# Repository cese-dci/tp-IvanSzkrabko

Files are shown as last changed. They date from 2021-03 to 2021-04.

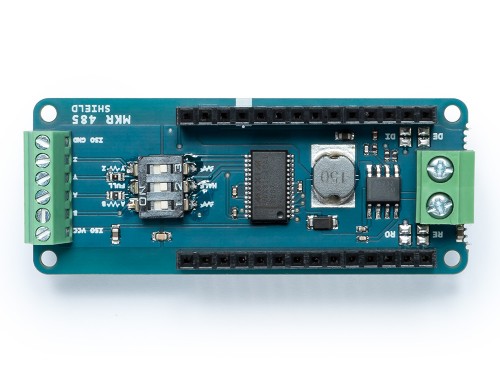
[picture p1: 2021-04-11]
Documentos/Superior.jpg

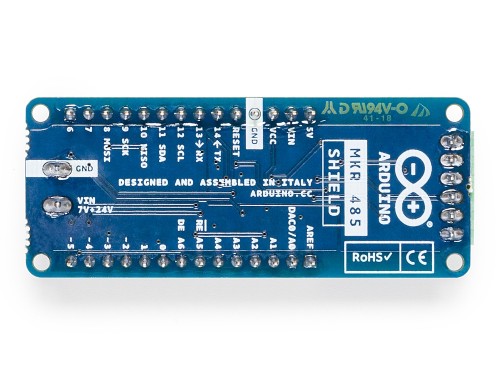
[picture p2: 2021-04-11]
Documentos/Inferior.jpg

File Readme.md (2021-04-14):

Shield RS485 para placa MKR1_Wifi1010
================================================

[][cc-by-sa]

This work is licensed under a
[Creative Commons Attribution-ShareAlike 4.0 International License][cc-by-sa].

[][cc-by-sa]

[cc-by-sa]: http://creativecommons.org/licenses/by-sa/4.0/
[cc-by-sa-image]: https://licensebuttons.net/l/by-sa/4.0/88x31.png
[cc-by-sa-shield]: https://img.shields.io/badge/License-CC%20BY--SA%204.0-lightgrey.svg

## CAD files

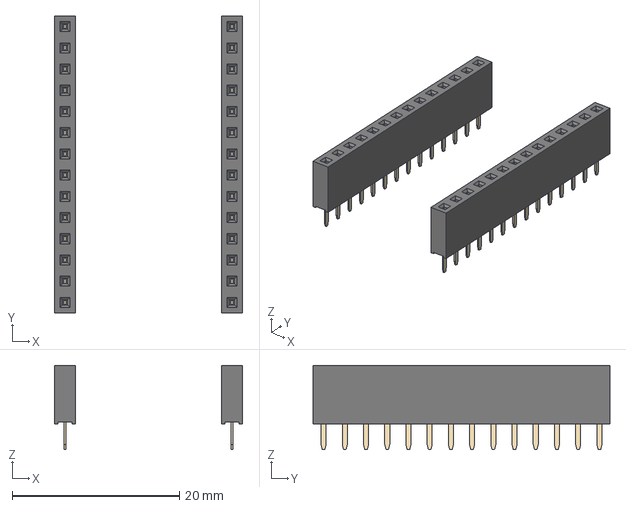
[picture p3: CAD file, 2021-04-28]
3dshapes/MKR_Sockets_v1.step
22.5 x 35.6 x 10.1 mm

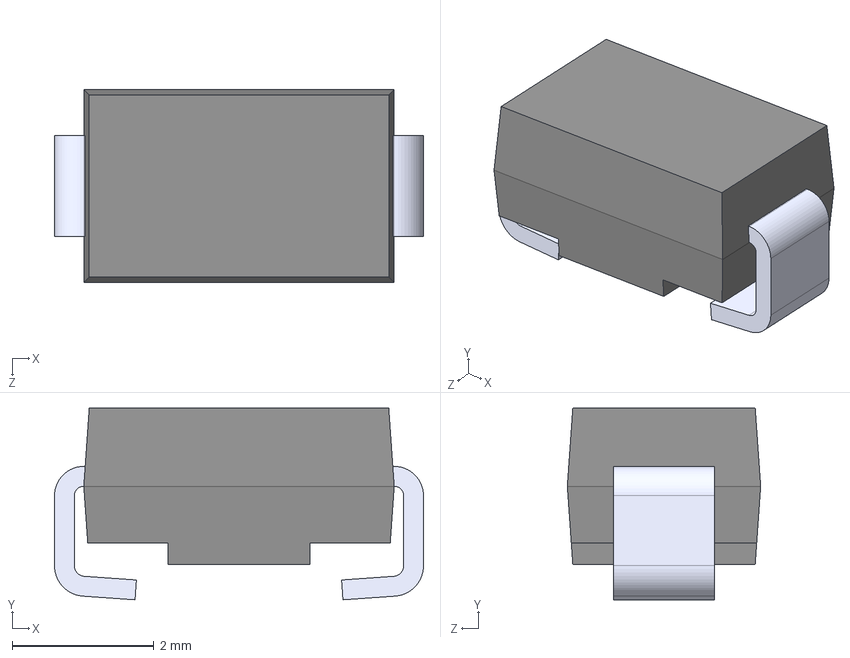
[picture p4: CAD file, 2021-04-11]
3dshapes/DO_214AC.step
5.20 x 2.70 x 2.73 mm

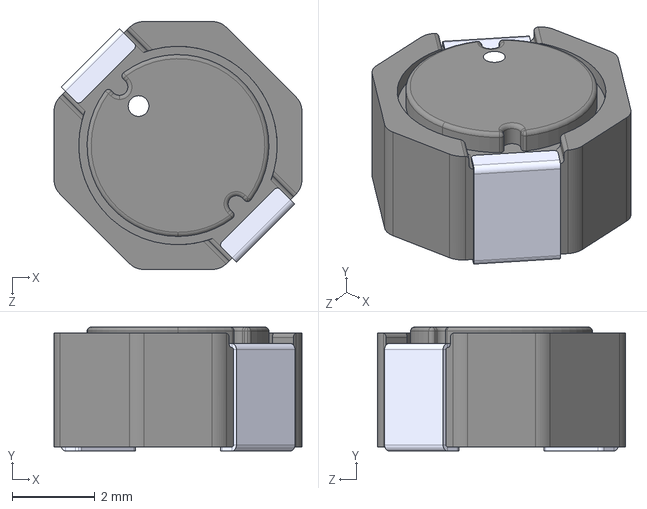
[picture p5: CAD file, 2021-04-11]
3dshapes/L_15uh.step
6.00 x 3.00 x 6.00 mm

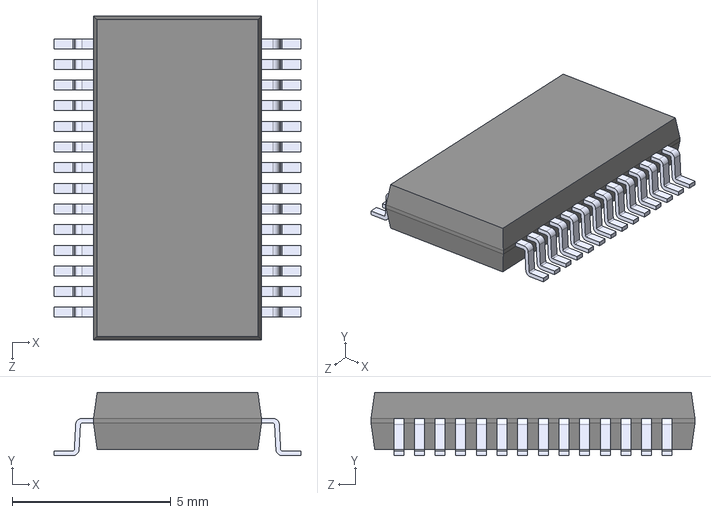
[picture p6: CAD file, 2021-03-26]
3dshapes/MAX3157CAI.step
7.78 x 1.99 x 10.2 mm

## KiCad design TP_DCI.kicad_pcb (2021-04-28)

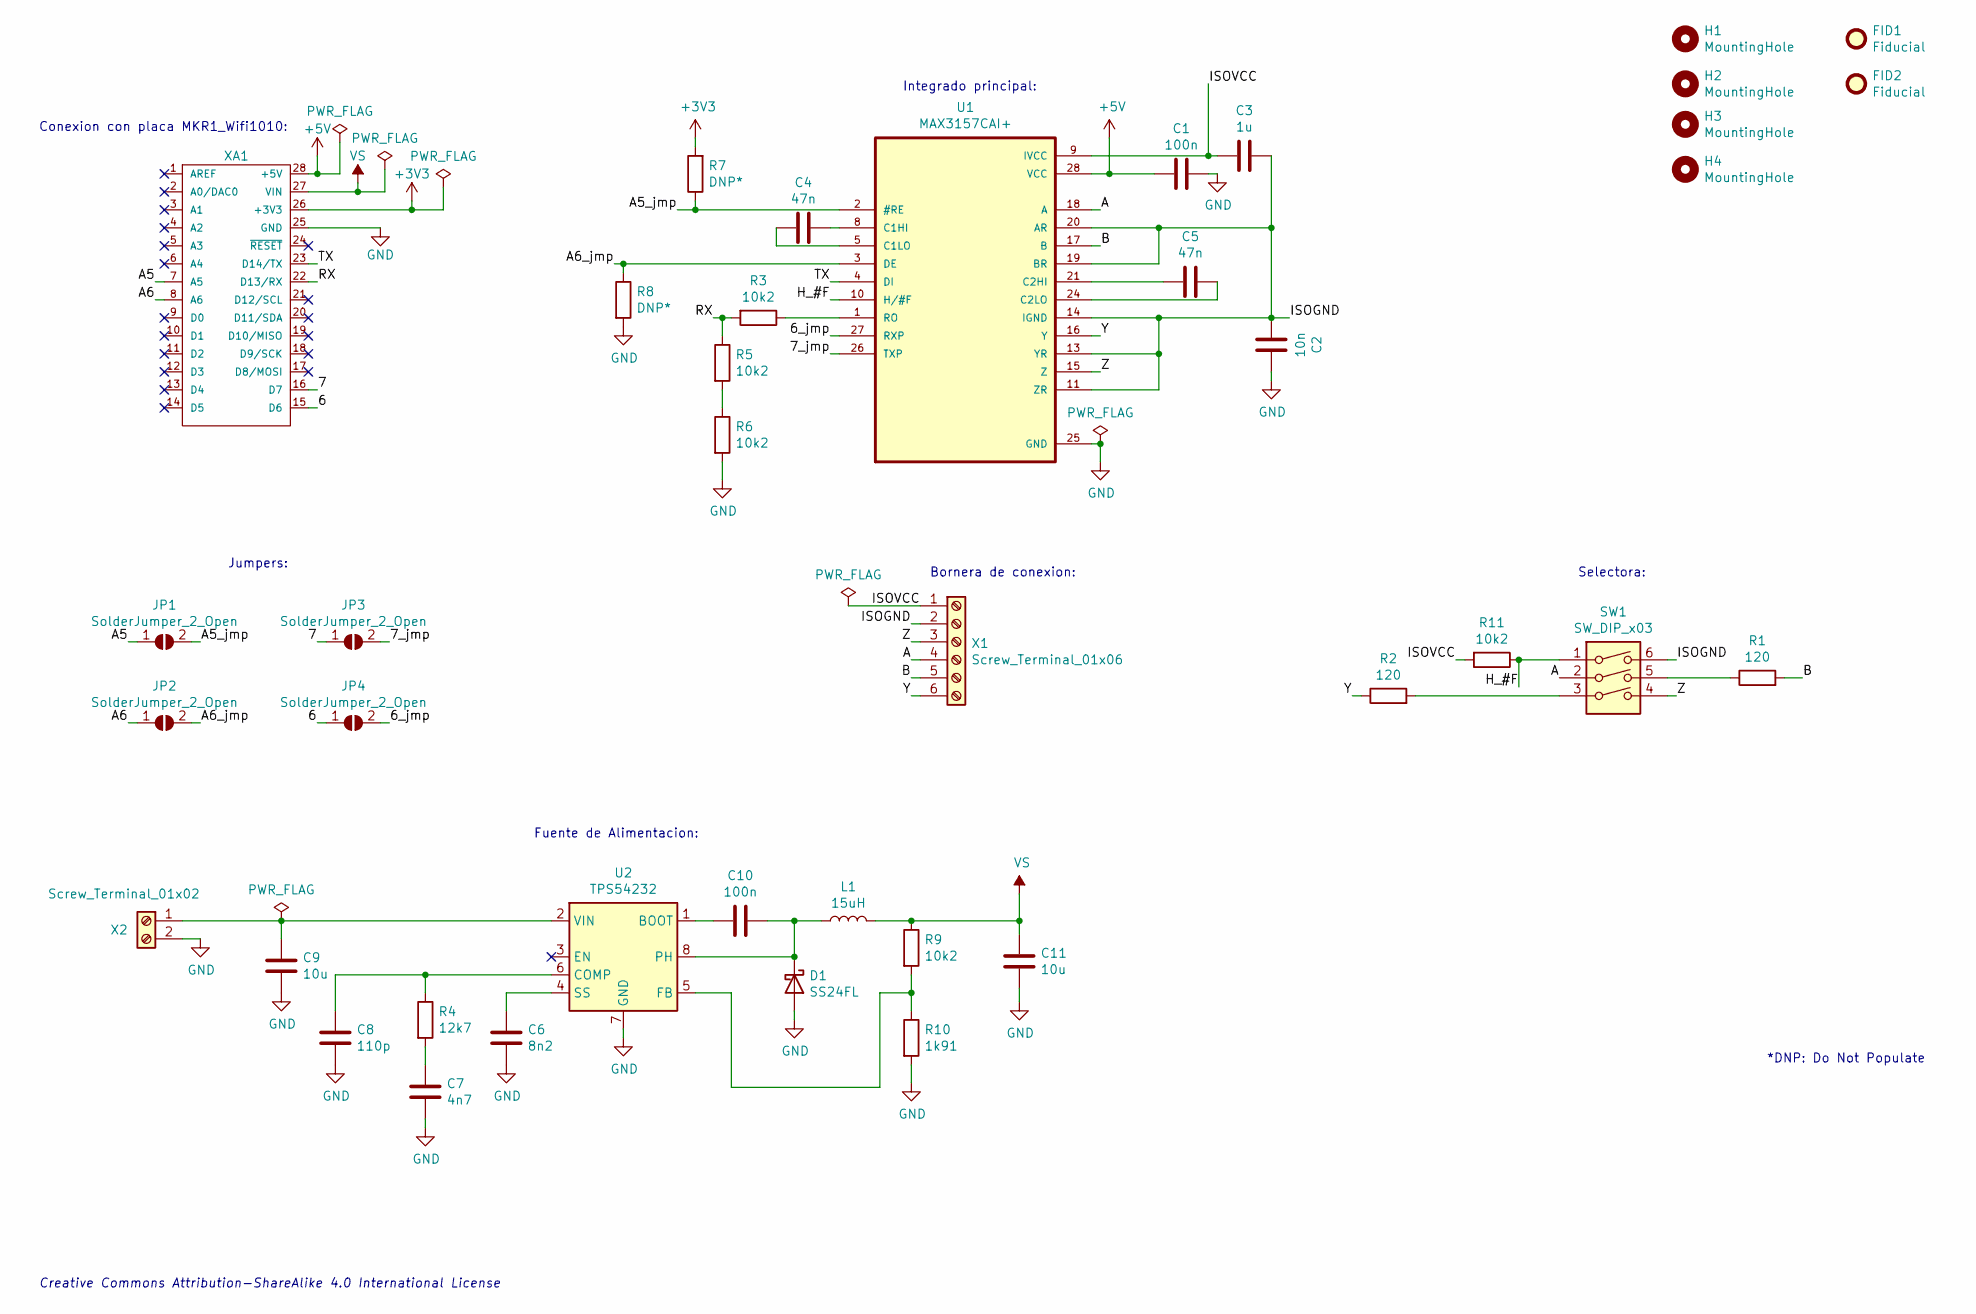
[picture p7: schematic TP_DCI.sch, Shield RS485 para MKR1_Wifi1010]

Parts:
C1: 100n; C_0805_2012Metric
C2: 10n; C_0805_2012Metric
C3: 1u; C_0805_2012Metric
C4, C5: 47n; C_0805_2012Metric
C6: 8n2; C_0805_2012Metric
C7: 4n7; C_0805_2012Metric
C8: 110p; CP_EIA-1608-08_AVX-J
C9, C11: 10u; C_0805_2012Metric
C10: 100n; CP_EIA-1608-08_AVX-J
D1: SS24FL; DO-214BA; Mouser 512-SS24FL
FID1, FID2: Fiducial; Fiducial_0.5mm_Mask1.5mm
H1, H2, H3, H4: MountingHole; MountingHole_2.1mm
JP1, JP2, JP3, JP4: SolderJumper_2_Open; SolderJumper-2_P1.3mm_Open_RoundedPad1.0x1.5mm
L1: 15uH; IND_#A921CY-150M=P3; Mouser 710-7447707150
R1, R2: 120; R_0805_2012Metric
R3, R5, R6, R9, R11: 10k2; R_0805_2012Metric
R4: 12k7; R_0805_2012Metric
R7, R8: DNP*; R_0805_2012Metric
R10: 1k91; R_0805_2012Metric
SW1: SW_DIP_x03; SW_DIP_SPSTx03_Slide_6.7x9.18mm_W7.62mm_P2.54mm_LowProfile; Mouser 490-DS01C-254-S-03BE
U1: MAX3157CAI+; SOP65P777X199-28N; Mouser 700-MAX3157CAI+
U2: TPS54232; SOIC-8_3.9x4.9mm_P1.27mm; Mouser 595-TPS54232D
X1: Screw_Terminal_01x06; TerminalBlock_Phoenix_MKDS-1,5-6-5.08_1x06_P5.08mm_Horizont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
X2: Screw_Terminal_01x02; TerminalBlock_bornier-2_P5.08mm
XA1: MKR1_WIFI_1010; MKR_WIFI_1010_Shield

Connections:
+3V3: R7.2, XA1.26 (+3V3)
+5V: C1.1, U1.28 (VCC), XA1.28 (+5V)
/6: JP4.1 (A), XA1.15 (D6)
/6_jmp: JP4.2 (B), U1.27 (RXP)
/7: JP3.1 (A), XA1.16 (D7)
/7_jmp: JP3.2 (B), U1.26 (TXP)
/A: SW1.2, U1.18 (A), X1.4
/A5: JP1.1 (A), XA1.7 (A5)
/A5_jmp: JP1.2 (B), R7.1, U1.2 (#RE)
/A6: JP2.1 (A), XA1.8 (A6)
/A6_jmp: JP2.2 (B), R8.1, U1.3 (DE)
/B: R1.2, U1.17 (B), X1.5
/H_#F: R11.1, SW1.1, U1.10 (H/#F)
/ISOGND: C2.2, C3.2, SW1.6, U1.11 (ZR), U1.13 (YR), U1.14 (IGND), U1.19 (BR), U1.20 (AR), X1.2
/ISOVCC: C3.1, R11.2, U1.9 (IVCC), X1.1
/RX: R3.2, R5.1, XA1.22 (D13/RX)
/TX: U1.4 (DI), XA1.23 (D14/TX)
/Y: R2.1, U1.16 (Y), X1.6
/Z: SW1.4, U1.15 (Z), X1.3
GND: C1.2, C2.1, C6.2, C7.2, C8.2, C9.2, C11.2, D1.2 (A), R6.2, R8.2, R10.2, U1.25 (GND), U2.7 (GND), X2.2, XA1.25 (GND)
unnamed: C4.1, U1.8 (C1HI)
unnamed: C4.2, U1.5 (C1LO)
unnamed: C5.1, U1.24 (C2LO)
unnamed: C5.2, U1.21 (C2HI)
unnamed: C6.1, U2.4 (SS)
unnamed: C7.1, R4.2
unnamed: C8.1, R4.1, U2.6 (COMP)
unnamed: C9.1, U2.2 (VIN), X2.1
unnamed: C10.1, U2.1 (BOOT)
unnamed: C10.2, D1.1 (K), L1.1, U2.8 (PH)
unnamed: R1.1, SW1.5
unnamed: R2.2, SW1.3
unnamed: R3.1, U1.1 (RO)
unnamed: R5.2, R6.1
unnamed: R9.2, R10.1, U2.5 (FB)
VS: C11.1, L1.2, R9.1, XA1.27 (VIN)

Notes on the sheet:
Fuente de Alimentacion:
Integrado principal:
*DNP: Do Not Populate
Conexion con placa MKR1_Wifi1010:
Jumpers:
Selectora:
Bornera de conexion:
Creative Commons Attribution-ShareAlike 4.0 International License

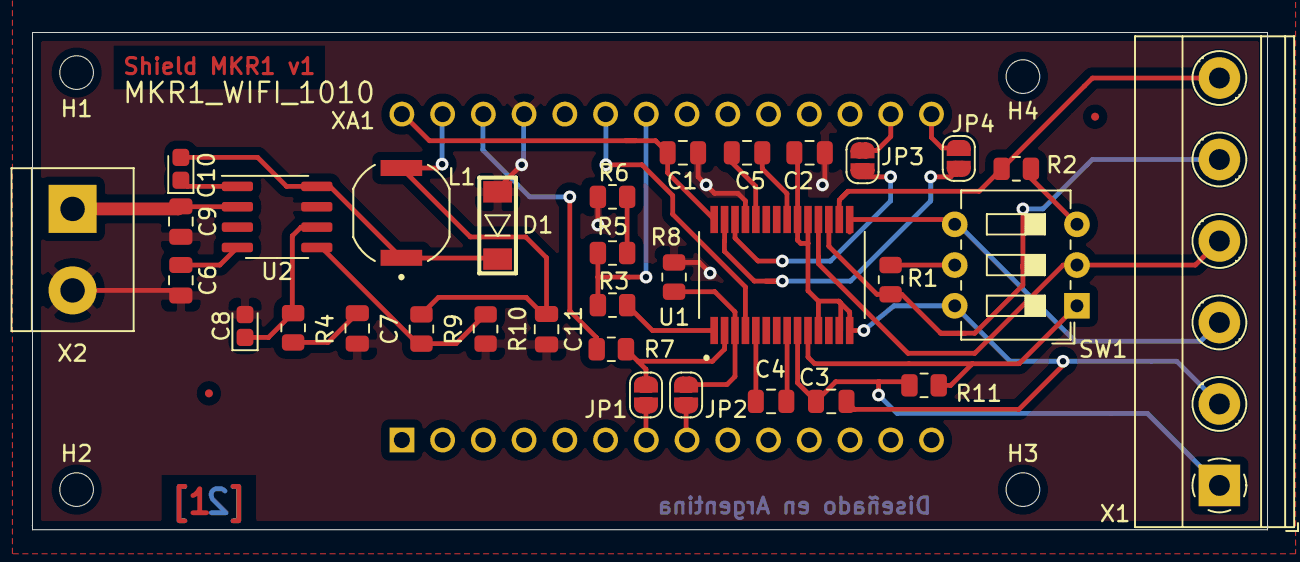
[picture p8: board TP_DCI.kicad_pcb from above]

Board: 2 copper layers, 77.0 x 31.0 mm, 40 parts (0 on the bottom side), 36 nets.

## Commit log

2021-03-26 avanzo con esquematico
    [MAX3157CAI_.step, TP_DCI.kicad_pcb, TP_DCI.sch]
2021-04-09 Avanzo con asociacion de footprints
    [TP_DCI.sch]
2021-04-11 Fin etapa 1, esquematico y asociacion de footprints
    [#A921CY-150M=P3.STEP, Arduino_-_MKR_WIFI_1010.step, S1B.step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]
2021-04-11 Para correccion Etapa 1
    [TP_DCI.kicad_pcb, TP_DCI.sch]
2021-04-14 Agrego correcciones de Gaspar
    [TP_DCI.kicad_pcb, TP_DCI.sch]
2021-04-14 Lista para correccion
    [TP_DCI.sch]
2021-04-14 Listo para revisar, agrego links a datasheets
    [TP_DCI.sch]
2021-04-16 Arranco con el PCB
    [TP_DCI.kicad_pcb, TP_DCI.sch]
2021-04-18 Version del PCB completa
    [TP_DCI.kicad_pcb, TP_DCI.sch]
2021-04-18 Version para correccion
    [TP_DCI.kicad_pcb]
2021-04-23 Version para corregir PCB
    [TP_DCI.kicad_pcb, TP_DCI.sch]
2021-04-24 Listo para correccion
    [TP_DCI.kicad_pcb, TP_DCI.sch]
2021-04-28 Agrego correcciones
    [TP_DCI.kicad_pcb, TP_DCI.sch]
2021-04-28 Agrego correcciones finales
    [Arduino_-_MKR_WIFI_1010.step, DO_214AC.step, L_15uh.step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]

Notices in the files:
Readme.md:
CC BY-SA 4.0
